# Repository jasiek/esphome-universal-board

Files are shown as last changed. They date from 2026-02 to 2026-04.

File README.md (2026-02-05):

# [esphome.io](https://esphome.io)-compatible universal board

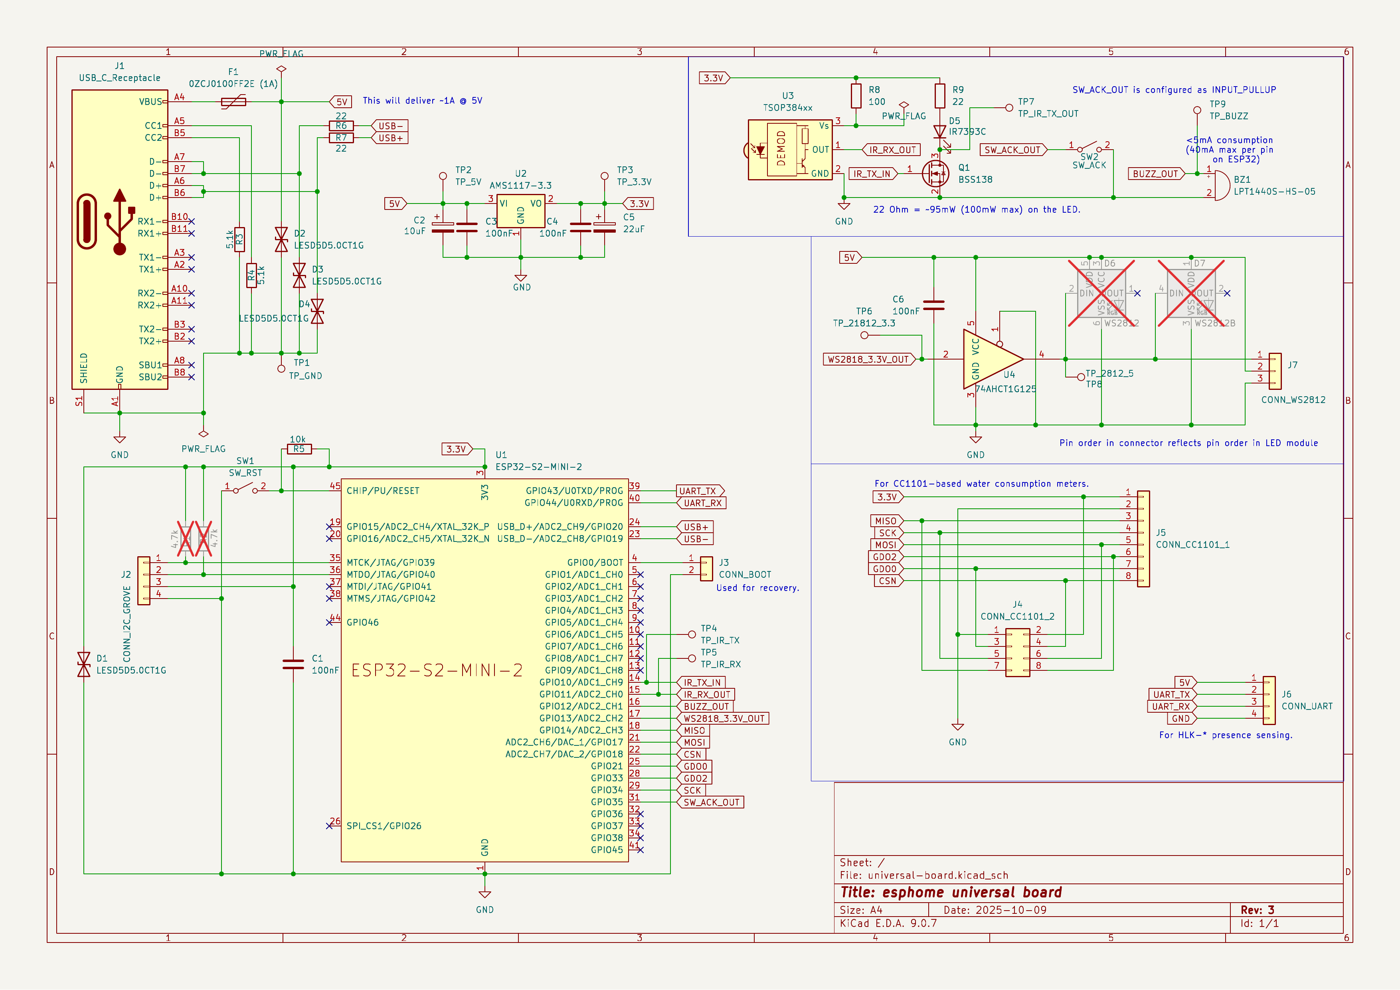
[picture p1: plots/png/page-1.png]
board


* Can control an air conditioning unit and read its remote to display current state of unit.
* Can drive multiple WS2812 LEDs to indicate something.
* Can drive a buzzer to indicate something.
* Notifications using the above can be acknowledged with a click of a button.
* Can read the state of a water meter which uses WMBUS using a CC1101 module.
* Can incorporate additional sensors via I2C.

## Parts

* ESP32 Module [ESP32-S3-WROOM-1](https://www.espressif.com/sites/default/files/documentation/esp32-s3-wroom-1_wroom-1u_datasheet_en.pdf)
* IR Receiver: [TSOP38438](https://www.vishay.com/docs/82491/tsop382.pdf)
* IR Transmitter 850nm @ 165mW: [LL-503SIRC2H-1BE](https://www.tme.eu/Document/bbc76b3f66c79fcebc4b2a3071fa53b8/LL-503SIRC2H-1BE.pdf)
* USB PD Controller: [CH224K](https://www.laskakit.cz/user/related_files/ch224ds1.pdf)
* CC1101 868MHz module: [Small](https://ae01.alicdn.com/kf/H425240e05325482f9e129bee543d8c9eR.jpg) or [Large](https://ae01.alicdn.com/kf/S28ad7d5c77624d52bd05b87e7f74fee7y.jpg)
* Level shifter: [74AHCT1G125](https://www.ti.com/lit/ds/symlink/sn74ahct1g125.pdf)
* Buzzer: [LPT1440S-HS-05](https://www.tme.eu/Document/ccb72bb5ba4b269fcfcf63562faa0900/LPT1440S-HS-05-4.0-12-R.pdf)
* Presence sensors
  * [HLK-LD2450](https://www.tinytronics.nl/product_files/006000_HLK-LD2450-Instruction-Manual.pdf)
  * [HLK-LD2402](https://drive.google.com/file/d/1SmigbSjFt1toA7W5wEuI2Qy-1CSR6PQn/view)
  * [HLK-LD2410](https://www.tinytronics.nl/product_files/006002_HLK-LD2410S_datasheet.pdf)

## Other

* [A Primer on USB Type-C® and USB Power Delivery Applications and Requirements](https://www.ti.com/lit/wp/slyy109b/slyy109b.pdf)

## TODO for rev 3

* Place everything on one side of the board!
* Use SMD electrolytic capacitors.
* Hook up the output of the WS2812 correctly.
* Holes in the board need to be slightly bigger.
* ~~22-33 ohm series resistors on the USB pins: USB-C <-> ESD <-> R <-> USB on ESP32.~~
* ~~Get rid of the 3A PSU circuit.~~
* ~~Replace LED transmitter with a 940nm part, for example TSAL6200 (narrow beam), OSI5LA56A1A, IR7393C (100mA), OSI5NE87B1A, IR323/H0-A, IR8294, OSI5LA7WA1B.~~
* ~~Add another footprint for WS2812B and WS2812S, so that either can be populated~~

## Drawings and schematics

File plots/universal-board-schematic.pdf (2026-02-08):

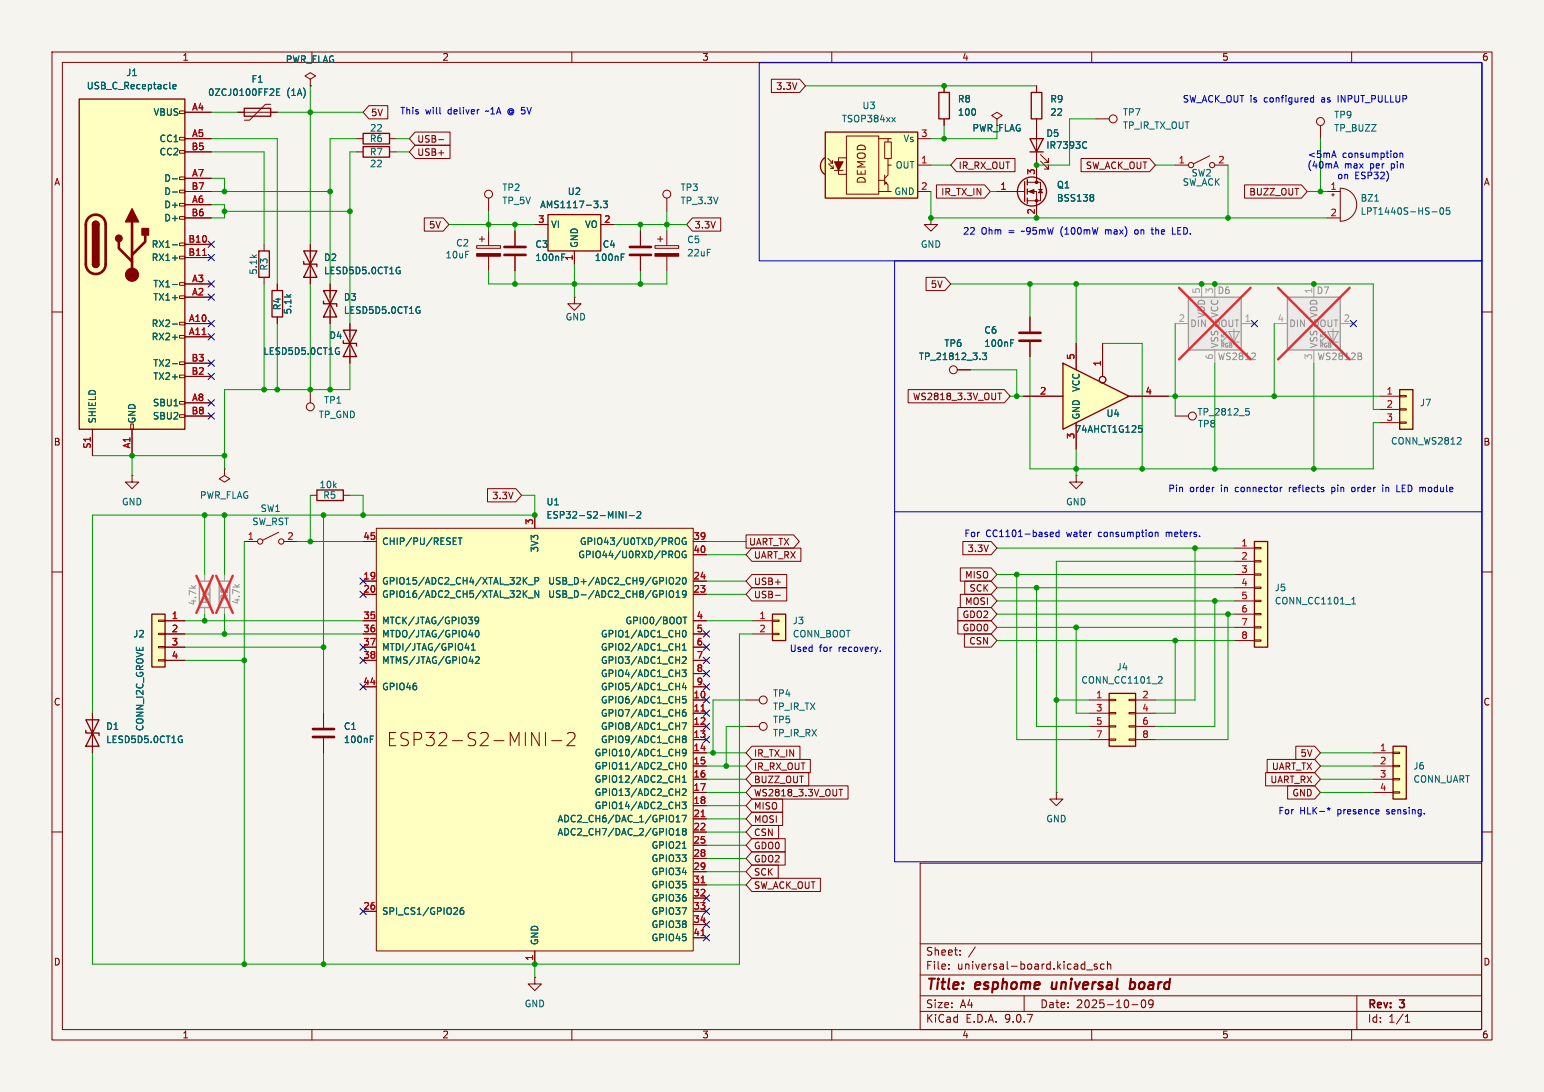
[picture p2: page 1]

22 Ohm = ~95mW (100mW max) on the LED. C6

3 GPIO43/U0TXD/PROG 39 GPIO44/U0RXD/PROG 40 USB_D+/ADC2_CH9/GPIO20 24 USB_D-/ADC2_CH8/GPIO19 23 GPIO0/BOOT 4 GPIO1/ADC1_CH0 5 GPIO2/ADC1_CH1 6 GPIO3/ADC1_CH2 7 GPIO4/ADC1_CH3 8 GPIO5/ADC1_CH4 9 GPIO6/ADC1_CH5 10 GPIO7/ADC1_CH6 11 GPIO8/ADC1_CH7 12 GPIO9/ADC1_CH8 13 GPIO10/ADC1_CH9 14 GPIO11/ADC2_CH0 15 GPIO12/ADC2_CH1 16 GPIO13/ADC2_CH2 17 GPIO14/ADC2_CH3 18 ADC2_CH6/DAC_1/GPIO17 21 ADC2_CH7/DAC_2/GPIO18 22 GPIO21 25 GPIO33 28 GPIO34 29 GPIO35 31 GPIO36 32 GPIO37 33 GPIO38 34 GPIO45 41 U1ESP32-S2-MINI-2 GND

1 GPIO15/ADC2_CH4/XTAL_32K_P 19 GPIO16/ADC2_CH5/XTAL_32K_N 20 MTCK/JTAG/GPIO39 35 MTDO/JTAG/GPIO40 36 MTDI/JTAG/GPIO41 37 MTMS/JTAG/GPIO42 38 SPI_CS1/GPIO26 26 3V3

File: universal-board.kicad_sch Sheet: /
Id: 1/1 Title: esphome universal board

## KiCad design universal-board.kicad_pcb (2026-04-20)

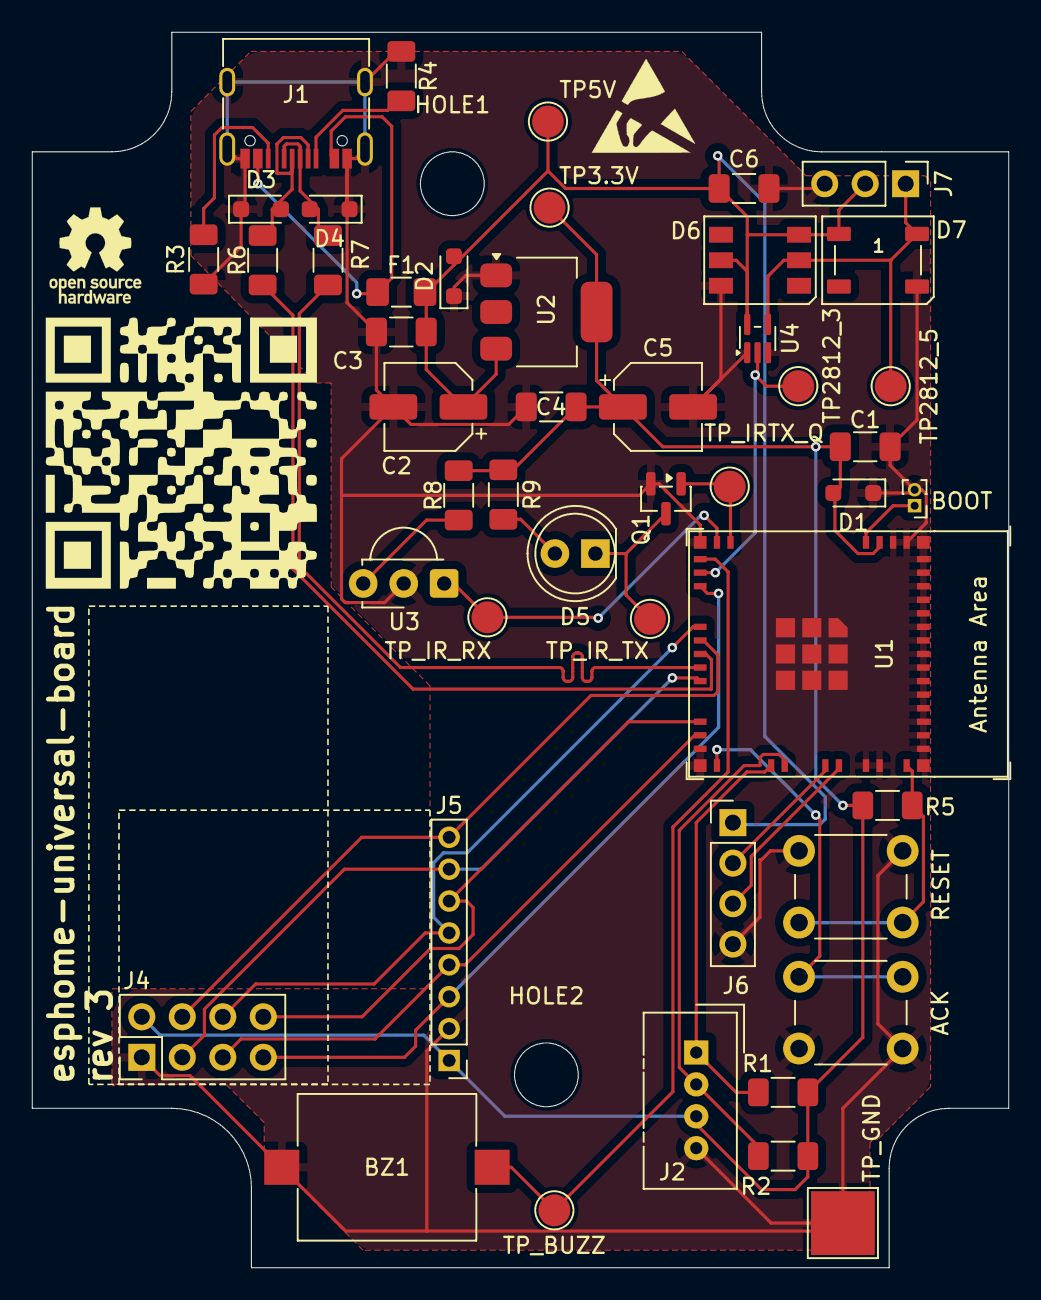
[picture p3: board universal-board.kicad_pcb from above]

Board: 2 copper layers, 61.2 x 77.5 mm, 49 parts (0 on the bottom side), 31 nets.

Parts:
ACK: SW_ACK; SW_PUSH_6mm
BOOT: CONN_BOOT; PinHeader_1x02_P1.00mm_Vertical
BZ1: LPT1440S-HS-05; Buzzer_Mallory_AST1109MLTRQ
C1, C3, C4, C6: 100nF; C_1206_3216Metric_Pad1.33x1.80mm_HandSolder
C2: 10uF; CP_Elec_5x5.4
C5: 22uF; CP_Elec_5x5.4
D1, D2, D3, D4: PESD5V0L1BA,115-ES; D_SOD-323_HandSoldering
D5: IR7393C; LED_D5.0mm_Clear
D6: WS2812; LED_WS2812_PLCC6_5.0x5.0mm_P1.6mm
D7: WS2812B; LED_WS2812B_PLCC4_5.0x5.0mm_P3.2mm
F1: 0ZCJ0100FF2E (1A); Fuse_1206_3216Metric_Pad1.42x1.75mm_HandSolder
HOLE1, HOLE2: MountingHole_4mm
J1: USB_C_Receptacle; USB_C_Receptacle_G-Switch_GT-USB-7010ASV
J2: CONN_I2C_GROVE; NS-Tech_Grove_1x04_P2mm_Vertical
J4: CONN_CC1101_2; PinHeader_2x04_P2.54mm_Vertical
J5: CONN_CC1101_1; PinHeader_1x08_P2.00mm_Vertical
J6: CONN_UART; PinHeader_1x04_P2.54mm_Vertical
J7: CONN_WS2812; PinHeader_1x03_P2.54mm_Vertical
Q1: BSS138; SOT-23
R1, R2: 4.7k; R_1206_3216Metric_Pad1.30x1.75mm_HandSolder
R3, R4: 5.1k; R_1206_3216Metric_Pad1.30x1.75mm_HandSolder
R5: 10k; R_1206_3216Metric_Pad1.30x1.75mm_HandSolder
R6, R7, R9: 22; R_1206_3216Metric_Pad1.30x1.75mm_HandSolder
R8: 100; R_1206_3216Metric_Pad1.30x1.75mm_HandSolder
RESET: SW_RST; SW_PUSH_6mm
TP3.3V: TP_3.3V; TestPoint_Pad_D2.0mm
TP5V: TP_5V; TestPoint_Pad_D2.0mm
TP2812_3: TP_21812_3.3; TestPoint_Pad_D2.0mm
TP2812_5: TP_2812_5; TestPoint_Pad_D2.0mm
TP_BUZZ: TP_BUZZ; TestPoint_Pad_D2.0mm
TP_GND: TP_GND; TestPoint_Pad_4.0x4.0mm
TP_IRTX_Q: TP_IR_TX; TestPoint_Pad_D2.0mm
TP_IR_RX: TP_IR_RX; TestPoint_Pad_D2.0mm
TP_IR_TX: TP_IR_TX_OUT; TestPoint_Pad_D2.0mm
U1: ESP32-S2-MINI-2; ESP32-S2-MINI-1
U2: AMS1117-3.3; SOT-223-3_TabPin2
U3: TSOP384xx; Vishay_MINICAST-3Pin
U4: 74AHCT1G125; SOT-353_SC-70-5

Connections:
3.3V: C1.1, C4.1, C5.1, D1.2 (A2), J2.3, J4.2, J5.1, R1.2, R2.1, R5.2, R8.1, R9.1, TP3.3V.1, U1.3 (3V3), U2.2 (VO)
5V: C2.1, C3.1, C6.1, D2.2 (A2), D6.3 (VCC), D6.5 (VDD), D7.1 (VDD), F1.2, J6.1, J7.2, TP5V.1, U2.3 (VI), U4.5 (VCC)
BUZZ_OUT: BZ1.1 (+), TP_BUZZ.1, U1.16 (GPIO12/ADC2_CH1)
CSN: J4.4, J5.8, U1.22 (ADC2_CH7/DAC_2/GPIO18)
GDO0: J4.3, J5.7, U1.25 (GPIO21)
GDO2: J4.8, J5.6, U1.28 (GPIO33)
GND: ACK.2 (B), BOOT.2, BZ1.2 (-), C1.2, C2.2, C3.2, C4.2, C5.2, C6.2, D1.1 (A1), D2.1 (A1), D3.1 (A1), D4.1 (A1), D6.6 (VSS), D7.3 (VSS), J1.A1 (GND), J1.A12 (GND), J1.B1 (GND), J1.B12 (GND), J1.S1 (SHIELD), J2.4, J4.1, J5.2, J6.4, J7.3, Q1.2 (S), R3.1, R4.2, RESET.1 (A), TP_GND.1, U1.1 (GND), U1.2 (GND), U1.30 (GND), U1.42 (GND), U1.43 (GND), U1.46 (GND), U1.47 (GND), U1.48 (GND), U1.49 (GND), U1.50 (GND), U1.51 (GND), U1.52 (GND), U1.53 (GND), U1.54 (GND), U1.55 (GND), U1.56 (GND), U1.57 (GND), U1.58 (GND), U1.59 (GND), U1.60 (GND), U1.61 (GND), U1.62 (GND), U1.63 (GND), U1.64 (GND), U1.65 (GND), U2.1 (GND), U3.2 (GND), U4.1, U4.3 (GND)
IR_RX_OUT: TP_IR_RX.1, U1.15 (GPIO11/ADC2_CH0), U3.1 (OUT)
IR_TX_IN: Q1.1 (G), TP_IRTX_Q.1, U1.14 (GPIO10/ADC1_CH9)
MISO: J4.7, J5.3, U1.18 (GPIO14/ADC2_CH3)
MOSI: J4.6, J5.5, U1.21 (ADC2_CH6/DAC_1/GPIO17)
unnamed: D3.2 (A2), J1.A7 (D-), J1.B7 (D-), R6.1
unnamed: D4.2 (A2), J1.A6 (D+), J1.B6 (D+), R7.1
unnamed: D5.2 (A), R9.2
unnamed: D5.1 (K), Q1.3 (D), TP_IR_TX.1
unnamed: D6.2 (DIN), D7.4 (DIN), J7.1, TP2812_5.1, U4.4
unnamed: F1.1, J1.A4 (VBUS), J1.A9 (VBUS), J1.B4 (VBUS), J1.B9 (VBUS)
unnamed: J1.A5 (CC1), R4.1
unnamed: J1.B5 (CC2), R3.2
unnamed: J2.1, R1.1, U1.35 (MTCK/JTAG/GPIO39)
unnamed: J2.2, R2.2, U1.36 (MTDO/JTAG/GPIO40)
unnamed: BOOT.1, U1.4 (GPIO0/BOOT)
unnamed: R5.1, RESET.2 (B), U1.45 (CHIP/PU/RESET)
unnamed: R8.2, U3.3 (Vs)
SCK: J4.5, J5.4, U1.29 (GPIO34)
SW_ACK_OUT: ACK.1 (A), U1.31 (GPIO35)
UART_RX: J6.3, U1.40 (GPIO44/U0RXD/PROG)
UART_TX: J6.2, U1.39 (GPIO43/U0TXD/PROG)
USB+: R7.2, U1.24 (USB_D+/ADC2_CH9/GPIO20)
USB-: R6.2, U1.23 (USB_D-/ADC2_CH8/GPIO19)
WS2818_3.3V_OUT: TP2812_3.1, U1.17 (GPIO13/ADC2_CH2), U4.2

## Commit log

2025-09-10 Schematic for everything.
    [led_array.kicad_sch, universal-board.kicad_sch]
2025-09-11 Final schematic before review.
    [cc1101_interface.kicad_sch, led_array.kicad_sch, peripherals.kicad_sch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]
2025-09-11 Place ~18–22 Ω (for ~100 mA pulsed) in series with D2.
    [peripherals.kicad_sch]
2025-09-11 Added TVS (SMAJ5.0A) to VBUS-GND Added polyfuses to both PSUs
    [psu_1a.kicad_sch, psu_high_power.kicad_sch, universal-board.kicad_sch]
2025-09-11 Use LPT1440S-HS-05 as the buzzer.
    [peripherals.kicad_sch]
2025-09-11 Shorted DM-DP on the CK224K (pins don't need to be wired up).
    [psu_high_power.kicad_sch, universal-board.kicad_sch]
2025-09-11 Fixed design error, 5V is connected to VBUS which is the controlled line.
    [psu_high_power.kicad_sch]
2025-09-11 Added 10k pull-up and 100nF cap between 3.3V/GND for EN.
    [universal-board.kicad_sch]
2025-09-11 Added USBLC6-2SC6 for CC1/CC2 lines.
    [universal-board.kicad_sch]
2025-09-11 Fixed design error IO10 connected to WS2812 input. Added do not connect markers.
    [universal-board.kicad_sch]
2025-09-11 Minor touches.
    [led_array.kicad_sch]
2025-09-11 Re-labelled all parts.
    [cc1101_interface.kicad_sch, led_array.kicad_sch, peripherals.kicad_sch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]
2025-09-28 ERC fixes.
    [led_array.kicad_sch, universal-board.kicad_pcb, universal-board.kicad_sch]
2025-09-28 Resolved all DRC errors
    [psu_high_power.kicad_sch]
2025-09-28 - added bidirectional TVS between VBUS & GND - USB-C shield and GND are now connected - added comments re pin order - removed pull-up resistor on SW_ACK_INPUT because it's configured as INPUT_PULLUP
    [peripherals.kicad_sch, psu_high_power.kicad_sch, universal-board.kicad_sch]
2025-09-28 Tied down CFG2,3 to GND.
    [psu_high_power.kicad_sch]
2025-09-29 Added decoupling caps for the AMS1117-3.3
    [psu_high_power.kicad_sch, universal-board.kicad_sch]
2025-09-29 Cap and resistor for TSOP384x
    [peripherals.kicad_sch]
2025-09-29 Added capacitor for ESP32/EN pin
    [universal-board.kicad_sch]
2025-09-29 Moved some components around for better readability.
    [led_array.kicad_sch, peripherals.kicad_sch, psu_high_power.kicad_sch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]
2025-09-29 Flipped grove connector around
    [universal-board.kicad_sch]
2025-09-29 Updated README.
    Reworked the circuit around CH224K per datasheet an example schematics.
    [peripherals.kicad_sch, psu_high_power.kicad_sch]
2025-10-09 Reorganized board to be on one sheet.
    [led_array.kicad_sch, peripherals.kicad_sch, psu_1a.kicad_sch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]
2025-10-09 Regenerated schematic.
2025-10-09 Remapped elements
    [universal-board.kicad_sch]
2025-10-09 ERC checks clean.
    [universal-board.kicad_sch]
2025-10-09 Rev 1, added test points
    [universal-board.kicad_sch]
2025-10-10 Partial footprint assignment.
    [universal-board.kicad_sch]
2025-12-17 PCB WIP
    [universal-board.kicad_pcb, universal-board.kicad_sch]
2025-12-24 Added UART for HLK modules.
    Updated TODO.
    [universal-board.kicad_sch]
2025-12-25 Removed unused schematics.
    [cc1101_interface.kicad_sch, led_array.kicad_sch, peripherals.kicad_sch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]
2025-12-25 Changed resistor footprints to be actual resistors.
    [universal-board.kicad_sch]
2025-12-25 Added footprint for GCT USB4105-GF-A
    [universal-board.kicad_sch]
2025-12-25 DRC passes on schematic.
    [universal-board.kicad_pcb, universal-board.kicad_sch]
2025-12-26 PCB is routed, but needs more work.
    [universal-board.kicad_pcb, universal-board.kicad_sch]
2025-12-26 Rerouted PCB with freeroute. DRC still pending.
    [universal-board.kicad_pcb]
2025-12-26 revision 1 - off to manufacturing
    [universal-board.kicad_pcb]
2025-12-27 - added QR code for test printing - made group labels more prominent - moved some components around to make DRC happy - connected unconnected components (!)
    marked as rev 2
    [universal-board.kicad_pcb]
2026-01-31 Prep for rev 3:
    - removed 3A PSU
    - added 2 33 ohm resistors for USB
    [universal-board.kicad_sch]
2026-02-03 Added reference designs for ESP32 modules.
    Adjusted IR LED part number.
    Added another WS2812.
    [universal-board.kicad_sch]
2026-02-05 Added TVS diodes to USB and resistors.
    [universal-board.kicad_sch]
2026-02-05 Used ESP32-S2-MINI-2 in place of the curret module.
    [universal-board.kicad_sch]
2026-02-06 Renumbered components.
    [universal-board.kicad_sch]
2026-02-06 Footprints assigned
    [universal-board.kicad_sch]
2026-02-06 Updated part number on schematic for ESP32
    [universal-board.kicad_sch]
2026-02-07 Added another ESD diode.
    [universal-board.kicad_sch]
2026-02-07 First stab at layout for rev 3
    [universal-board.kicad_pcb, universal-board.kicad_sch]
2026-02-07 Routing done, pending DRC
    [universal-board.kicad_pcb]
2026-02-07 Schematic update (plots).
2026-02-08 Refreshed plot.
    [universal-board.kicad_pcb]
2026-02-17 Further minor changes to make DRC happy.
    [universal-board.kicad_pcb]
2026-04-20 Changed TVS diodes to ElecSuper PESD5V0L1BA,115-ES (bigger, easier to solder).
    [universal-board.kicad_pcb, universal-board.kicad_sch]
